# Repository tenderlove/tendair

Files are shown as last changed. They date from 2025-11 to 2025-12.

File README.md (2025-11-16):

# Tendair

Tendair is a CO2 / Temp / RH / PM2.5 / VOC / NOx sensor hooked up to an ESP32.

It's basically just [this sensor](https://sensirion.com/media/documents/FAFC548D/68C12881/Sensirion_Datasheet_SEN6x.pdf)
with [this micro controller](https://www.digikey.com/en/products/detail/espressif-systems/ESP32-C3-WROOM-02-H4/14553033)

Here is a photo:

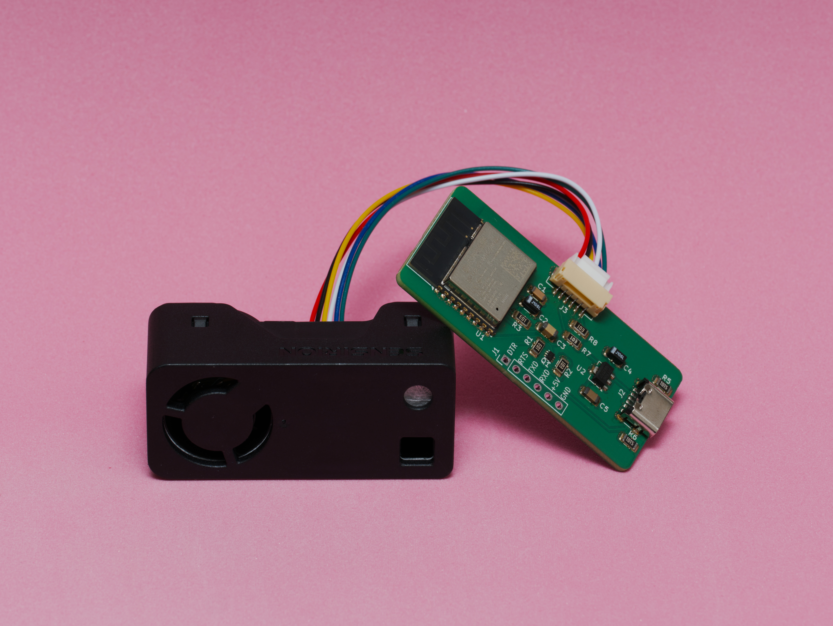
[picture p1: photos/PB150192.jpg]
Tendair photo


This is basically just a new version of my [ESP8266 AQ sensor](https://github.com/tenderlove/esp8266aq).

I haven't made an enclosure yet, I'm working on that now.

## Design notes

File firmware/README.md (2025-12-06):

# Flashing firmware

First [install esp-idf](https://docs.espressif.com/projects/esp-idf/en/stable/esp32/get-started/index.html).

Then do:

```
idf.py set-target esp32-c3
idf.py menuconfig
```

Select `Tendair Configuration` and change the Wifi SSID and Wifi password.
Set the MQTT Prefix, I use "/home/main/office" for my office that is on the
main floor of my house.

Also set the MQTT uri, which should be the URI of the MQTT server you've set up.

Then:

```
idk.py build flash
```

## Writing to InfluxDB

Use `tools/mqtt-to-influx.rb` to subscribe to the messages and write them to
InfluxDB

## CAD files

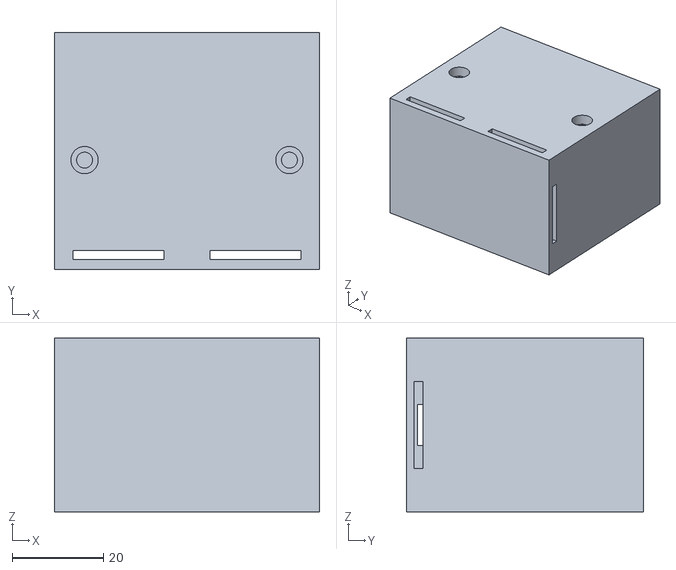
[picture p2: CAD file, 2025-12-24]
enclosure/full.stl
58.2 x 52.0 x 38.2

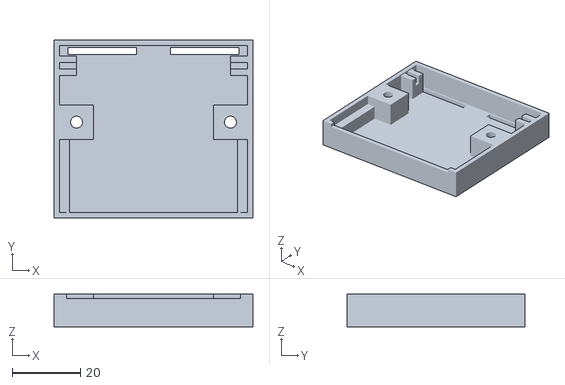
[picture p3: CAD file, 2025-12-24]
enclosure/top.stl
58.2 x 52.0 x 9.60

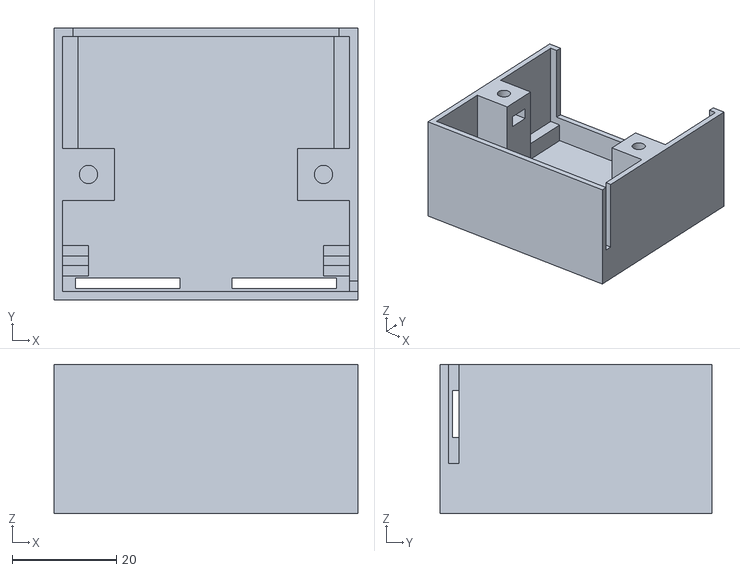
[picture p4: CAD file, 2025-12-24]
enclosure/bottom.stl
58.2 x 52.0 x 28.6

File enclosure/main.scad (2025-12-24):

LAYER_HEIGHT = 0.2;
PCB_X = 55;
PCB_Y = 1.8;
PARTS_Y = 5;
PCB_Z = 26;
WALL_THICKNESS = 1.6;

PCB_BUFFER_Z = 4.5;

GAP = 20; // Gap between PCB and sensor

SEN66_X = 55; // Hopefully
SEN66_Y = 22; // Hopefully
SEN66_Z = 25.5; // Hopefully

inner_x = PCB_X;
inner_y = PCB_Y + PARTS_Y + SEN66_Y + GAP;
inner_z = PCB_Z + (PCB_BUFFER_Z * 2);

SEN66_BUFFER_Z = (inner_z - SEN66_Z) / 2;

BOLT_DIAMETER = 3.5;
BOLT_HEAD_DIAMETER = 6;
BOLT_HEAD_HEIGHT = 3;
NUT_FLAT_TO_FLAT = 5.4;
NUT_LENGTH = 3;
FROM_BOLT_BOTTOM = 20;
POST_SIZE = 10;

USB_X = WALL_THICKNESS + 1;
USB_Y = 4.2;
USB_Z = 9;

module BoltNegative(post_size, nominal_length, head_length) {
    flat_to_flat = NUT_FLAT_TO_FLAT;
    bolt_diameter = BOLT_DIAMETER;
    head_diameter = BOLT_HEAD_DIAMETER;
    from_bolt_bottom = FROM_BOLT_BOTTOM;
    nut_length = NUT_LENGTH;

    corner_to_corner = flat_to_flat * 1.1547;

    union() {
        // Bridges for nut slot
        translate([0, 0, from_bolt_bottom + nut_length + LAYER_HEIGHT])
            linear_extrude(LAYER_HEIGHT)
            square(size = [bolt_diameter, bolt_diameter], center = true);

        // Bridges for nut slot
        translate([0, 0, from_bolt_bottom + nut_length - 0.1])
            linear_extrude(LAYER_HEIGHT + 0.1)
            square(size = [bolt_diameter, flat_to_flat], center = true);

        // Slot for nut
        color("pink")
            translate([-((((post_size - corner_to_corner) / 2) / 2) + 0.1), 0, from_bolt_bottom])
            linear_extrude(nut_length)
            square(size = [corner_to_corner + ((post_size - corner_to_corner) / 2) + 0.1, flat_to_flat], center = true);

        // Bolt head sink
        color("blue")
            translate([0, 0, nominal_length])
            linear_extrude(head_length + 1)
            circle(d = head_diameter, $fn = 50);

        // Bridges for head
        translate([0, 0, nominal_length - LAYER_HEIGHT])
            linear_extrude(LAYER_HEIGHT)
            square(size = [bolt_diameter, head_diameter], center = true);

        // Bridges for head
        translate([0, 0, nominal_length - (LAYER_HEIGHT * 2)])
            linear_extrude(LAYER_HEIGHT)
            square(size = [bolt_diameter, bolt_diameter], center = true);

        // Bolt shaft
        color("green")
            translate([0, 0, 0])
            linear_extrude(nominal_length + 1)
            circle(d = bolt_diameter, $fn = 50);
    }
}

module BoltPositive(post_size, nominal_length, head_length) {
    difference() {
        linear_extrude(nominal_length + head_length)
            square(size = post_size, center = true);
    }
}

module BoltPostsPositive(width, height) {
    post_size = POST_SIZE;
    post_height = height;

    move = (width / 2) - (post_size / 2);

    translate([move, 0, 0])
        BoltPositive(post_size, post_height - BOLT_HEAD_HEIGHT, BOLT_HEAD_HEIGHT);

    translate([-move, 0, 0])
        rotate(180)
        BoltPositive(post_size, post_height - BOLT_HEAD_HEIGHT, BOLT_HEAD_HEIGHT);
}

module BoltPostsNegative(width, height) {
    post_size = POST_SIZE;
    post_height = height;

    move = (width / 2) - (post_size / 2);

    for (i = [0, 180]) {
        for (j = [1, -1]) {
            translate([j * move, 0, 0])
                rotate(i)
                BoltNegative(post_size, post_height - BOLT_HEAD_HEIGHT, BOLT_HEAD_HEIGHT);
        }
    }
}

module Main() {
    difference() {
        // Exterior
        translate([0, 0, -WALL_THICKNESS])
            linear_extrude(inner_z + (WALL_THICKNESS * 2))
            square(size = [inner_x + (WALL_THICKNESS * 2), inner_y + (WALL_THICKNESS * 2)], center = true);

        // Interior
        linear_extrude(inner_z)
            square(size = [inner_x, inner_y], center = true);
    }
}

module BottomPCBTabs(tab_x, tab_y, tab_z) {
    for (i = [1, -1]) {
        translate([i * ((PCB_X / 2) - (tab_x / 2)), 0, -PCB_BUFFER_Z])
            linear_extrude(PCB_BUFFER_Z)
            square(size = [tab_x, tab_y * 2 + PCB_Y], center = true);
        for (j = [1, -1]) {
            translate([i * ((PCB_X / 2) - (tab_x / 2)), j * (((tab_y / 2) + (PCB_Y / 2))), 0])
                linear_extrude(tab_z)
                square(size = [tab_x, tab_y], center = true);
        }
    }
}

module PCBTabs() {
    tab_z = 3;
    tab_y = 2;
    tab_x = 5;

    translate([0, 0, (PCB_Z / 2) + PCB_BUFFER_Z]) {
        rotate([180, 0, 0])
            translate([0, 0, -PCB_Z / 2])
            BottomPCBTabs(tab_x, tab_y, tab_z);
        translate([0, 0, -PCB_Z / 2])
            BottomPCBTabs(tab_x, tab_y, tab_z);
    }
}

module FullBox() {
    difference() {
        union() {
            Main();
            translate([0, (-POST_SIZE / 2) + (inner_z - POST_SIZE - SEN66_Y), 0])
                BoltPostsPositive(inner_x, inner_z + WALL_THICKNESS);

            translate([0, (-(inner_y / 2)) + (PCB_Y / 2) + PARTS_Y, 0])
                PCBTabs();
            translate([0, (inner_y / 2) - SEN66_Y, 0])
                SEN66Tabs();
        }

        // Bolt cutouts
        translate([0, (-POST_SIZE / 2) + (inner_z - POST_SIZE - SEN66_Y), 0])
            BoltPostsNegative(inner_x, inner_z + WALL_THICKNESS);

        SensorWindow();

        translate([0, (-(inner_y / 2)) + PARTS_Y - (USB_Y / 2), 0])
            USBWindow();

        Vents();
    }
}

module BottomSlice() {
    difference() {
        FullBox();

        zshift = (PCB_BUFFER_Z + (PCB_Z / 2) + USB_Z / 2) + 5;

        translate([0, 0, zshift])
            linear_extrude(60)
            square(size = 60, center = true);
    }
}

module TopSlice() {
    intersection() {
        FullBox();

        zshift = (PCB_BUFFER_Z + (PCB_Z / 2) + USB_Z / 2) + 5;

        translate([0, 0, zshift])
            linear_extrude(60)
            square(size = 60, center = true);
    }
}

module SEN66Tabs() {
    rail_x = 3;
    translate([0, SEN66_Y / 2, (SEN66_Z / 2) + SEN66_BUFFER_Z]) {
        //color("purple")
        //    cube([SEN66_X, SEN66_Y, SEN66_Z], center = true);

        for (j = [1, -1]) {
            for (i = [1, -1]) {
                xoffset = i * ((SEN66_X / 2) - (rail_x / 2));
                zoffset = j * ((SEN66_Z / 2) + (SEN66_BUFFER_Z / 2));
                translate([xoffset, 0, zoffset])
                    cube(size = [rail_x, SEN66_Y, SEN66_BUFFER_Z], center = true);
            }
        }
    }
}

module SensorWindow() {
    translate([0, (inner_y / 2) + (WALL_THICKNESS / 2), SEN66_BUFFER_Z + 2])
        linear_extrude(SEN66_Z - 4)
        square(size = [SEN66_X - 4, WALL_THICKNESS + 2], center = true);
}

module USBWindow() {
    usb_move_z = (PCB_Z / 2) - (USB_Z / 2) + PCB_BUFFER_Z;
    translate([-((PCB_X / 2) + (USB_X / 2)) + 0.5, 0, usb_move_z])
        linear_extrude(USB_Z)
        square(size = [USB_X, USB_Y], center = true);
}

module Vents() {
    z = PCB_Z - 7;
    xoffset = (inner_x / 2) + WALL_THICKNESS - (WALL_THICKNESS / 2);
    zoffset = (inner_z / 2) - (z / 2);
    yoffset = -(inner_y / 2) + 1;

    // Top Vent
    translate([xoffset, yoffset, zoffset])
        linear_extrude(z)
        square(size = [WALL_THICKNESS + 0.2, 2], center = true);

    total_z = inner_z + (WALL_THICKNESS * 2);
    translate([0, -(inner_y / 2) + 1.6, (total_z / 2) - WALL_THICKNESS])
        for(j = [15, -15]) {
            for(i = [1, -1]) {
                translate([j, 0, i * (total_z / 2)])
                    cube([20, 2, WALL_THICKNESS+ 5], center = true);
            }
        }
}

rendering = "full";

if (rendering == "top") {
    translate([0, 60, 35])
        rotate([180, 0, 0])
        TopSlice();
}

if (rendering == "bottom") {
    BottomSlice();
}

if (rendering == "full") {
    FullBox();
}

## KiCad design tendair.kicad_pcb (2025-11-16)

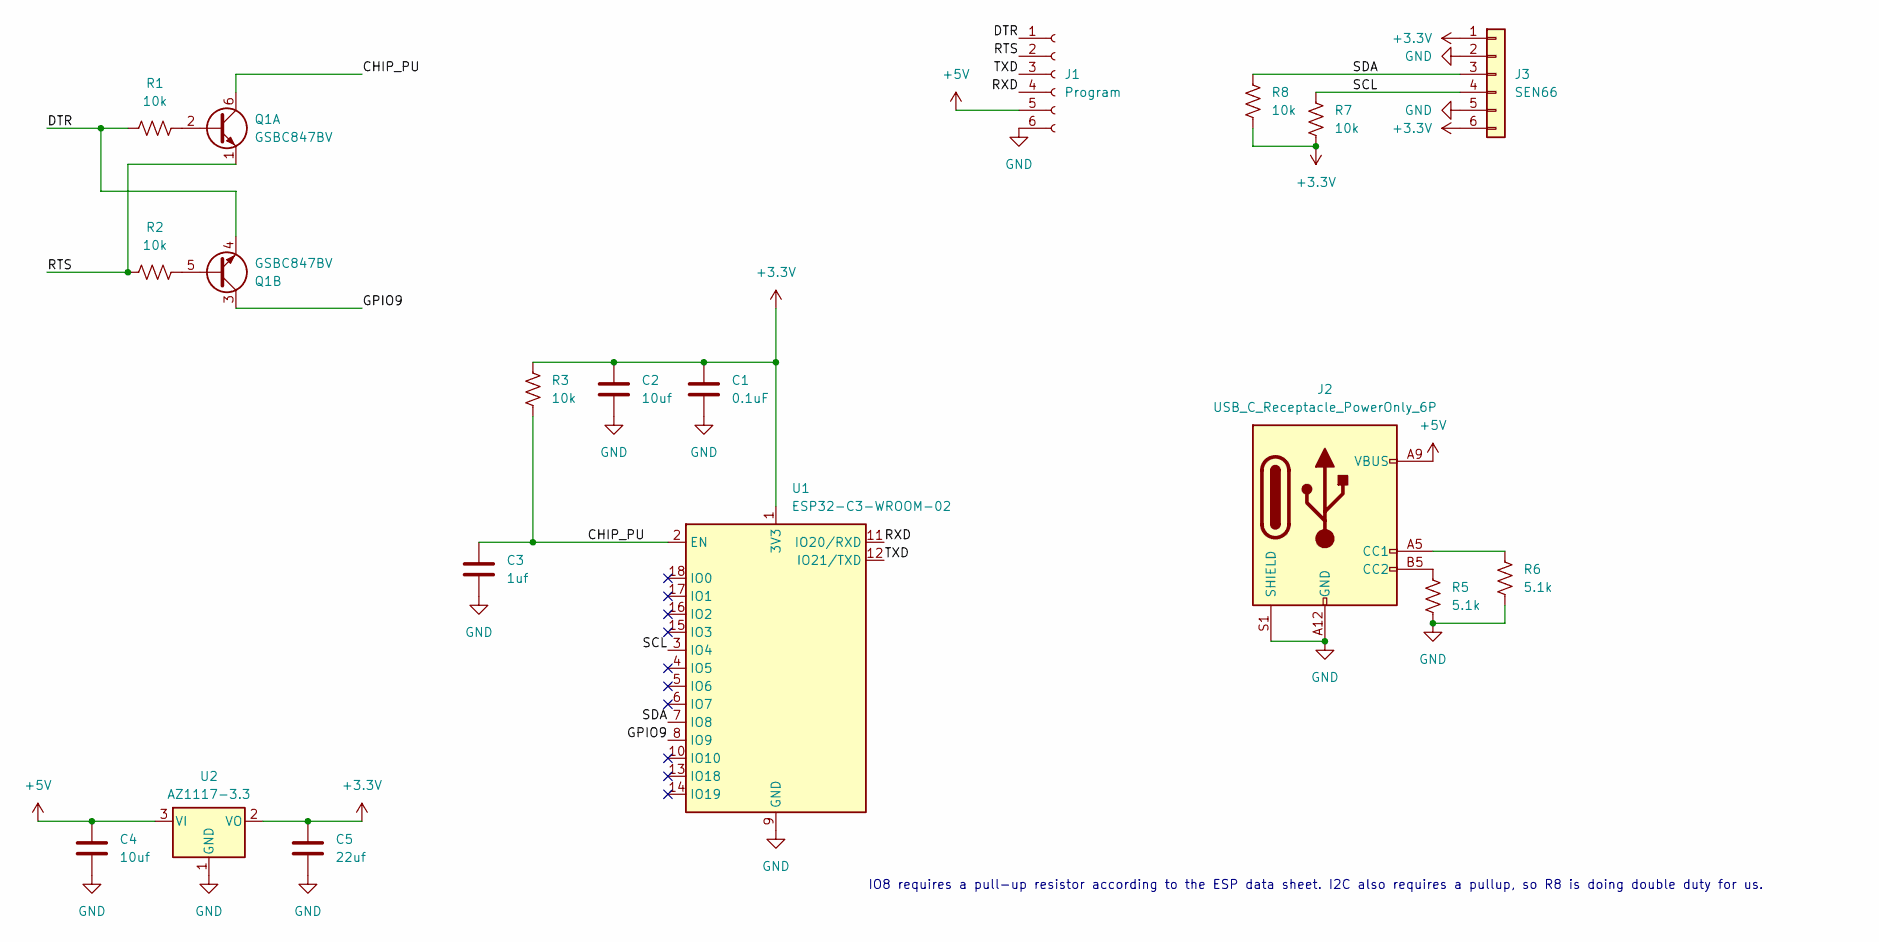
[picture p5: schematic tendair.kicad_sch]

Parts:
C1: 0.1uF; C_1206_3216Metric
C2, C4: 10uf; C_1206_3216Metric
C3: 1uf; C_1206_3216Metric
C5: 22uf; C_1206_3216Metric
J1: Program; PinHeader_1x06_P2.54mm_Vertical
J2: USB_C_Receptacle_PowerOnly_6P; USB_C_Receptacle_GCT_USB4125-xx-x_6P_TopMnt_Horizontal
J3: SEN66; JST_GH_SM06B-GHS-TB_1x06-1MP_P1.25mm_Horizontal
Q1: GSBC847BV; SOT-563
R1, R2, R3, R7, R8: 10k; R_1206_3216Metric
R5, R6: 5.1k; R_1206_3216Metric
U1: ESP32-C3-WROOM-02
U2: AZ1117-3.3; SOT-89-3

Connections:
+3.3V: C1.1, C2.1, C5.1, J3.1, J3.6, R3.1, R7.2, R8.2, U1.1 (3V3), U2.2 (VO)
+5V: C4.1, J1.5, J2.A9 (VBUS), J2.B9 (VBUS), U2.3 (VI)
/CHIP_PU: C3.1, Q1.6 (C1), R3.2, U1.2 (EN)
/DTR: J1.1, Q1.4 (E2), R1.1
/GPIO9: Q1.3 (C2), U1.8 (IO9)
/RTS: J1.2, Q1.1 (E1), R2.1
/RXD: J1.4, U1.11 (IO20/RXD)
/SCL: J3.4, R7.1, U1.3 (IO4)
/SDA: J3.3, R8.1, U1.7 (IO8)
/TXD: J1.3, U1.12 (IO21/TXD)
GND: C1.2, C2.2, C3.2, C4.2, C5.2, J1.6, J2.A12 (GND), J2.B12 (GND), J2.S1 (SHIELD), J3.2, J3.5, R5.2, R6.2, U1.9 (GND), U1.19 (GND), U2.1 (GND)
unnamed: J2.A5 (CC1), R6.1
unnamed: J2.B5 (CC2), R5.1
unnamed: Q1.2 (B1), R1.2
unnamed: Q1.5 (B2), R2.2

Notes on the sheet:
IO8 requires a pull-up resistor according to the ESP data sheet. I2C also requires a pullup, so R8 is doing double duty for us.

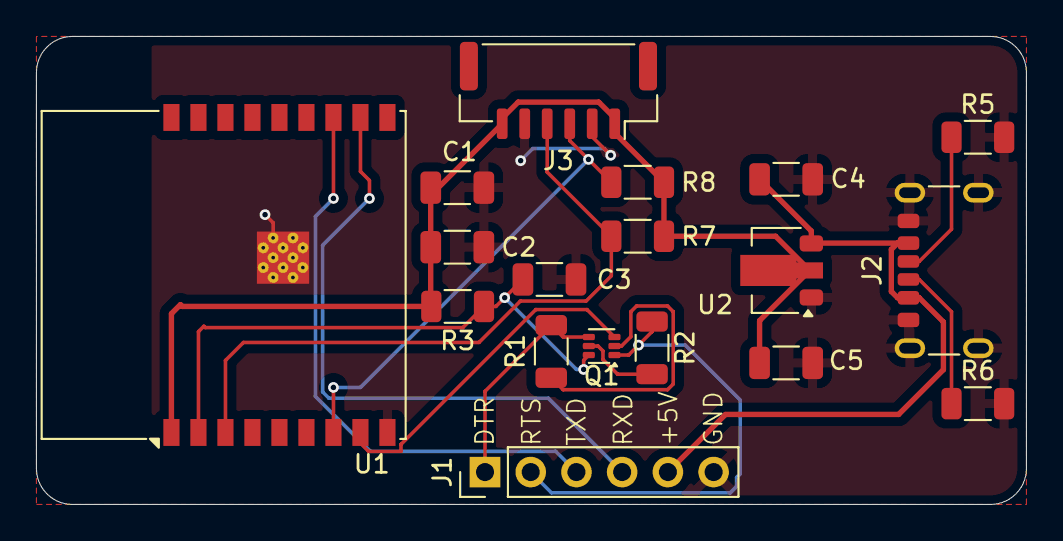
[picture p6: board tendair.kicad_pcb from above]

Board: 2 copper layers, 55.0 x 26.0 mm, 18 parts (0 on the bottom side), 15 nets.

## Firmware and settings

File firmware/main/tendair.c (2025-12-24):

#include <stdio.h>
#include "freertos/FreeRTOS.h"
#include "freertos/task.h"
#include "driver/i2c_master.h"
#include "esp_log.h"
#include "esp_wifi.h"
#include "esp_netif.h"
#include "mqtt_client.h"
#include "nvs_flash.h"
#include "sen66_i2c.h"
#include "sensirion_common.h"
#include "sensirion_i2c_hal.h"
#include "cJSON.h"

static const char *TAG = "tendair";

/* FreeRTOS event group to signal when we are connected*/
static EventGroupHandle_t s_wifi_event_group;

/* The event group allows multiple bits for each event, but we only care about two events:
 * - we are connected to the AP with an IP
 * - we failed to connect after the maximum amount of retries */
#define WIFI_CONNECTED_BIT BIT0
#define WIFI_FAIL_BIT      BIT1

#define MQTT_PREFIX CONFIG_MQTT_PREFIX

static int s_retry_num = 0;

static void log_error_if_nonzero(const char *message, int error_code)
{
    if (error_code != 0) {
        ESP_LOGE(TAG, "Last error %s: 0x%x", message, error_code);
    }
}

static void event_handler(void* arg, esp_event_base_t event_base,
                                int32_t event_id, void* event_data)
{
    if (event_base == WIFI_EVENT && event_id == WIFI_EVENT_STA_START) {
        esp_wifi_connect();
    } else if (event_base == WIFI_EVENT && event_id == WIFI_EVENT_STA_DISCONNECTED) {
        if (s_retry_num < 3) {
            esp_wifi_connect();
            s_retry_num++;
            ESP_LOGI(TAG, "retry to connect to the AP");
        } else {
            xEventGroupSetBits(s_wifi_event_group, WIFI_FAIL_BIT);
        }
        ESP_LOGI(TAG,"connect to the AP fail");
    } else if (event_base == IP_EVENT && event_id == IP_EVENT_STA_GOT_IP) {
        ip_event_got_ip_t* event = (ip_event_got_ip_t*) event_data;
        ESP_LOGI(TAG, "got ip:" IPSTR, IP2STR(&event->ip_info.ip));
        s_retry_num = 0;
        xEventGroupSetBits(s_wifi_event_group, WIFI_CONNECTED_BIT);
    }
}

void wifi_init_sta(void)
{
    s_wifi_event_group = xEventGroupCreate();

    ESP_ERROR_CHECK(esp_netif_init());

    ESP_ERROR_CHECK(esp_event_loop_create_default());
    esp_netif_create_default_wifi_sta();

    wifi_init_config_t cfg = WIFI_INIT_CONFIG_DEFAULT();
    ESP_ERROR_CHECK(esp_wifi_init(&cfg));

    esp_event_handler_instance_t instance_any_id;
    esp_event_handler_instance_t instance_got_ip;
    ESP_ERROR_CHECK(esp_event_handler_instance_register(WIFI_EVENT,
                                                        ESP_EVENT_ANY_ID,
                                                        &event_handler,
                                                        NULL,
                                                        &instance_any_id));
    ESP_ERROR_CHECK(esp_event_handler_instance_register(IP_EVENT,
                                                        IP_EVENT_STA_GOT_IP,
                                                        &event_handler,
                                                        NULL,
                                                        &instance_got_ip));

    wifi_config_t wifi_config = {
        .sta = {
            .ssid = CONFIG_WIFI_SSID,
            .password = CONFIG_WIFI_PASS,
            /* Authmode threshold resets to WPA2 as default if password matches WPA2 standards (password len => 8).
             * If you want to connect the device to deprecated WEP/WPA networks, Please set the threshold value
             * to WIFI_AUTH_WEP/WIFI_AUTH_WPA_PSK and set the password with length and format matching to
             * WIFI_AUTH_WEP/WIFI_AUTH_WPA_PSK standards.
             */
            .threshold.authmode = WIFI_AUTH_WPA2_PSK,
            .sae_pwe_h2e = WPA3_SAE_PWE_UNSPECIFIED,
            .sae_h2e_identifier = "",
#ifdef CONFIG_ESP_WIFI_WPA3_COMPATIBLE_SUPPORT
            .disable_wpa3_compatible_mode = 0,
#endif
        },
    };
    ESP_ERROR_CHECK(esp_wifi_set_mode(WIFI_MODE_STA) );
    ESP_ERROR_CHECK(esp_wifi_set_config(WIFI_IF_STA, &wifi_config) );
    ESP_ERROR_CHECK(esp_wifi_start() );

    ESP_LOGI(TAG, "wifi_init_sta finished.");

    /* Waiting until either the connection is established (WIFI_CONNECTED_BIT) or connection failed for the maximum
     * number of re-tries (WIFI_FAIL_BIT). The bits are set by event_handler() (see above) */
    EventBits_t bits = xEventGroupWaitBits(s_wifi_event_group,
            WIFI_CONNECTED_BIT | WIFI_FAIL_BIT,
            pdFALSE,
            pdFALSE,
            portMAX_DELAY);

    /* xEventGroupWaitBits() returns the bits before the call returned, hence we can test which event actually
     * happened. */
    if (bits & WIFI_CONNECTED_BIT) {
        ESP_LOGI(TAG, "connected to ap SSID:%s", CONFIG_WIFI_SSID);
    } else if (bits & WIFI_FAIL_BIT) {
        ESP_LOGI(TAG, "Failed to connect to SSID:%s", CONFIG_WIFI_SSID);
    } else {
        ESP_LOGE(TAG, "UNEXPECTED EVENT");
    }
}

static void mqtt_event_handler(void *handler_args, esp_event_base_t base, int32_t event_id, void *event_data)
{
    ESP_LOGD(TAG, "Event dispatched from event loop base=%s, event_id=%" PRIi32 "", base, event_id);
    esp_mqtt_event_handle_t event = event_data;
    esp_mqtt_client_handle_t client = event->client;
    int msg_id;
    switch ((esp_mqtt_event_id_t)event_id) {
    case MQTT_EVENT_CONNECTED:
        ESP_LOGI(TAG, "MQTT_EVENT_CONNECTED");
        break;

    case MQTT_EVENT_DISCONNECTED:
        ESP_LOGI(TAG, "MQTT_EVENT_DISCONNECTED");
        break;

    case MQTT_EVENT_SUBSCRIBED:
        ESP_LOGI(TAG, "MQTT_EVENT_SUBSCRIBED, msg_id=%d, return code=0x%02x ", event->msg_id, (uint8_t)*event->data);
        msg_id = esp_mqtt_client_publish(client, "/topic/qos0", "data", 0, 0, 0);
        ESP_LOGI(TAG, "sent publish successful, msg_id=%d", msg_id);
        break;
    case MQTT_EVENT_UNSUBSCRIBED:
        ESP_LOGI(TAG, "MQTT_EVENT_UNSUBSCRIBED, msg_id=%d", event->msg_id);
        break;
    case MQTT_EVENT_PUBLISHED:
        ESP_LOGD(TAG, "MQTT_EVENT_PUBLISHED, msg_id=%d", event->msg_id);
        break;
    case MQTT_EVENT_DATA:
        ESP_LOGI(TAG, "MQTT_EVENT_DATA");
        printf("TOPIC=%.*s\r\n", event->topic_len, event->topic);
        printf("DATA=%.*s\r\n", event->data_len, event->data);
        break;
    case MQTT_EVENT_ERROR:
        ESP_LOGI(TAG, "MQTT_EVENT_ERROR");
        if (event->error_handle->error_type == MQTT_ERROR_TYPE_TCP_TRANSPORT) {
            log_error_if_nonzero("reported from esp-tls", event->error_handle->esp_tls_last_esp_err);
            log_error_if_nonzero("reported from tls stack", event->error_handle->esp_tls_stack_err);
            log_error_if_nonzero("captured as transport's socket errno",  event->error_handle->esp_transport_sock_errno);
            ESP_LOGI(TAG, "Last errno string (%s)", strerror(event->error_handle->esp_transport_sock_errno));

        }
        break;
    default:
        ESP_LOGI(TAG, "Other event id:%d", event->event_id);
        break;
    }
}

void app_main(void)
{
    //Initialize NVS
    esp_err_t ret = nvs_flash_init();
    if (ret == ESP_ERR_NVS_NO_FREE_PAGES || ret == ESP_ERR_NVS_NEW_VERSION_FOUND) {
      ESP_ERROR_CHECK(nvs_flash_erase());
      ret = nvs_flash_init();
    }
    ESP_ERROR_CHECK(ret);

    i2c_master_bus_handle_t bus_handle;
    sensirion_i2c_hal_init(&bus_handle);
    ESP_LOGI(TAG, "I2C initialized successfully");

    // Starts the sensor
    sen66_start_continuous_measurement();

    ESP_LOGI(TAG, "ESP_WIFI_MODE_STA");
    wifi_init_sta();

    esp_mqtt_client_config_t mqtt_cfg = {
        .broker.address.uri = CONFIG_MQTT_URI,
    };

    esp_mqtt_client_handle_t client = esp_mqtt_client_init(&mqtt_cfg);
    /* The last argument may be used to pass data to the event handler, in this example mqtt_event_handler */
    esp_mqtt_client_register_event(client, ESP_EVENT_ANY_ID, mqtt_event_handler, NULL);
    esp_mqtt_client_start(client);

    uint8_t padding;
    bool ready;
    uint16_t mass_concentration_pm1p0;
    uint16_t mass_concentration_pm2p5;
    uint16_t mass_concentration_pm4p0;
    uint16_t mass_concentration_pm10p0;
    int16_t ambient_humidity;
    int16_t ambient_temperature;
    int16_t voc_index;
    int16_t nox_index;
    uint16_t co2;

    // Loop until everything is warmed up
    while (true) {
        if (!sen66_get_data_ready(&padding, &ready) && ready) {
            if (sen66_read_measured_values_as_integers(
                        &mass_concentration_pm1p0,
                        &mass_concentration_pm2p5,
                        &mass_concentration_pm4p0,
                        &mass_concentration_pm10p0,
                        &ambient_humidity,
                        &ambient_temperature,
                        &voc_index,
                        &nox_index,
                        &co2) == NO_ERROR) {

                if (mass_concentration_pm1p0 != 0xFFFF &&
                        mass_concentration_pm2p5 != 0xFFFF &&
                        mass_concentration_pm4p0 != 0xFFFF &&
                        mass_concentration_pm10p0 != 0xFFFF &&
                        ambient_humidity != 0x7FFF &&
                        ambient_temperature != 0x7FFF &&
                        voc_index != 0x7FFF &&
                        nox_index != 0x7FFF &&
                        co2 != 0xFFFF) {
                    break;
                }
            }
        }

        vTaskDelay(200 / portTICK_PERIOD_MS);
    }

    while (true) {
        if (!sen66_get_data_ready(&padding, &ready) && ready) {
            if (sen66_read_measured_values_as_integers(
                        &mass_concentration_pm1p0,
                        &mass_concentration_pm2p5,
                        &mass_concentration_pm4p0,
                        &mass_concentration_pm10p0,
                        &ambient_humidity,
                        &ambient_temperature,
                        &voc_index,
                        &nox_index,
                        &co2) == NO_ERROR) {

                cJSON *root = cJSON_CreateObject();
                cJSON_AddNumberToObject(root, "pm1.0", mass_concentration_pm1p0);
                cJSON_AddNumberToObject(root, "pm2.5", mass_concentration_pm2p5);
                cJSON_AddNumberToObject(root, "pm4.0", mass_concentration_pm4p0);
                cJSON_AddNumberToObject(root, "pm10.0", mass_concentration_pm10p0);
                cJSON_AddNumberToObject(root, "humidity", ambient_humidity / 100.0);
                cJSON_AddNumberToObject(root, "temperature", ambient_temperature / 200.0);
                cJSON_AddNumberToObject(root, "voc_index", voc_index / 10.0);
                cJSON_AddNumberToObject(root, "nox_index", nox_index / 10.0);
                cJSON_AddNumberToObject(root, "co2", co2);

                char *json_string = cJSON_Print(root);
                if (json_string != NULL) {
                    esp_mqtt_client_publish(client, MQTT_PREFIX "/measurement", json_string, 0, 1, 0);
                    cJSON_free(json_string);
                }
                cJSON_Delete(root);
            }
        }

        vTaskDelay(200 / portTICK_PERIOD_MS);
    }

    printf("Restarting now.\n");
    fflush(stdout);
    esp_restart();
}

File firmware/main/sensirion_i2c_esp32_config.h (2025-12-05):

/*
 * Copyright (c) 2023, Sensirion AG
 * All rights reserved.
 *
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
 * * Neither the name of Sensirion AG nor the names of its
 *   contributors may be used to endorse or promote products derived from
 *   this software without specific prior written permission.
 *
 * THIS SOFTWARE IS PROVIDED BY THE COPYRIGHT HOLDERS AND CONTRIBUTORS "AS IS"
 * AND ANY EXPRESS OR IMPLIED WARRANTIES, INCLUDING, BUT NOT LIMITED TO, THE
 * IMPLIED WARRANTIES OF MERCHANTABILITY AND FITNESS FOR A PARTICULAR PURPOSE
 * ARE DISCLAIMED. IN NO EVENT SHALL THE COPYRIGHT HOLDER OR CONTRIBUTORS BE
 * LIABLE FOR ANY DIRECT, INDIRECT, INCIDENTAL, SPECIAL, EXEMPLARY, OR
 * CONSEQUENTIAL DAMAGES (INCLUDING, BUT NOT LIMITED TO, PROCUREMENT OF
 * SUBSTITUTE GOODS OR SERVICES; LOSS OF USE, DATA, OR PROFITS; OR BUSINESS
 * INTERRUPTION) HOWEVER CAUSED AND ON ANY THEORY OF LIABILITY, WHETHER IN
 * CONTRACT, STRICT LIABILITY, OR TORT (INCLUDING NEGLIGENCE OR OTHERWISE)
 * ARISING IN ANY WAY OUT OF THE USE OF THIS SOFTWARE, EVEN IF ADVISED OF THE
 * POSSIBILITY OF SUCH DAMAGE.
 */

#ifndef SENSIRION_I2C_ESP32_CONFIG_H
#define SENSIRION_I2C_ESP32_CONFIG_H

#define I2C_MASTER_SCL_IO           CONFIG_I2C_MASTER_SCL
#define I2C_MASTER_SDA_IO           CONFIG_I2C_MASTER_SDA
#define I2C_MASTER_NUM              I2C_NUM_0
#define I2C_MASTER_FREQ_HZ          CONFIG_I2C_MASTER_FREQUENCY
#define I2C_MASTER_TX_BUF_DISABLE   0
#define I2C_MASTER_RX_BUF_DISABLE   0
#define I2C_MASTER_TIMEOUT_MS       1000

#define SEN66_SENSOR_ADDR         0x6B

#ifdef __cplusplus
extern "C" {
#endif

typedef int esp_err_t;

struct esp32_i2c_config {
    uint32_t freq;
    uint8_t addr;
    i2c_port_t port;
    gpio_num_t sda;
    gpio_num_t scl;
    bool sda_pullup;
    bool scl_pullup;
};

extern esp_err_t sensirion_i2c_config_esp32(struct esp32_i2c_config* cfg);
extern esp_err_t sensirion_i2c_esp32_ok(void);

#ifdef __cplusplus
}
#endif

#endif /* SENSIRION_I2C_ESP32_CONFIG_H */

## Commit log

2025-11-08 initial schematics
    [tendair.kicad_pcb, tendair.kicad_sch]
2025-11-09 updating the pcb
    [tendair.kicad_pcb, tendair.kicad_sch]
2025-11-16 update schematic
2025-11-16 add some drawings
    [tendair.kicad_pcb]
2025-11-22 adding bolt posts
    [main.scad]
2025-11-22 Happy with bolt posts
    [main.scad]
2025-11-23 Looking better
    [main.scad]
2025-11-23 Sensiron part seems to fit
    [main.scad]
2025-11-23 made window
    [main.scad]
2025-11-23 almost there
    [main.scad]
2025-11-23 Mostly done. Added Makefile
    [main.scad]
2025-11-23 add rendered stl files
    [bottom.stl, full.stl, top.stl]
2025-11-24 this works well!
    [bottom.stl, full.stl, main.scad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]
2025-12-05 log all samples via JSON to mqtt
2025-12-24 lifting the nut up a little
    [bottom.stl, full.stl, main.scad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]
2026-10-23 esphome: add SEN66 config using the sen6x platform
    Set the device name per board with `esphome -s name <name>`.
    Assisted-by: Claude Opus 5.5 via Claude Code
2026-10-23 Simplify the PM sensor names
